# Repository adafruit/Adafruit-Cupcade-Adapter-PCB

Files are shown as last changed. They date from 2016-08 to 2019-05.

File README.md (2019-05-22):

## Adafruit Cupcade Arcade Adapter V1 PCB
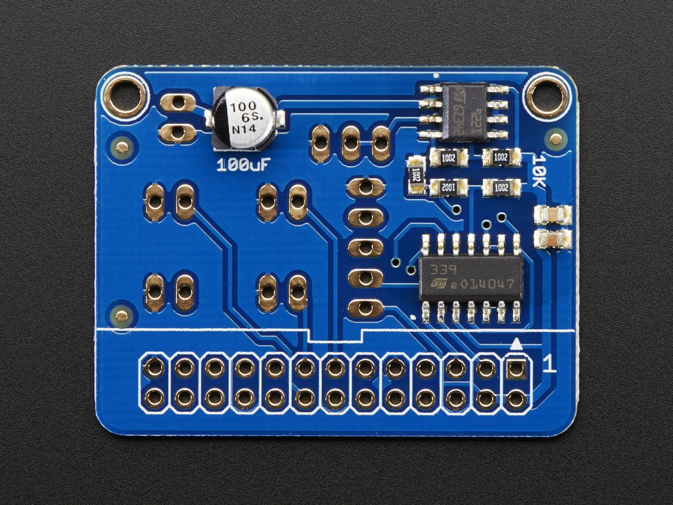
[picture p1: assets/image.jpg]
<a href="http://www.adafruit.com/products/1916"><br/>
Click here to purchase one from the Adafruit shop</a>

This is the PCB and small parts pack from original V1 Cupcade. These parts were used with the original "Raspberry Pi 1" design, not the version for Pi A+, 2, 3, or Zero!

Great for anyone who needs a replacement PCB or wants to mod or build out their Cupcade. 

PCB files for the Adafruit Cupcade Adapter. The format is EagleCAD schematic and board layout
- http://www.adafruit.com/product/1916

### License

Adafruit invests time and resources providing this open source design, please support Adafruit and open-source hardware by purchasing products from [Adafruit](https://www.adafruit.com)!

All text above must be included in any redistribution

Designed by Limor Fried/Ladyada for Adafruit Industries.
Creative Commons Attribution/Share-Alike, all text above must be included in any redistribution. 
See license.txt for additional information.

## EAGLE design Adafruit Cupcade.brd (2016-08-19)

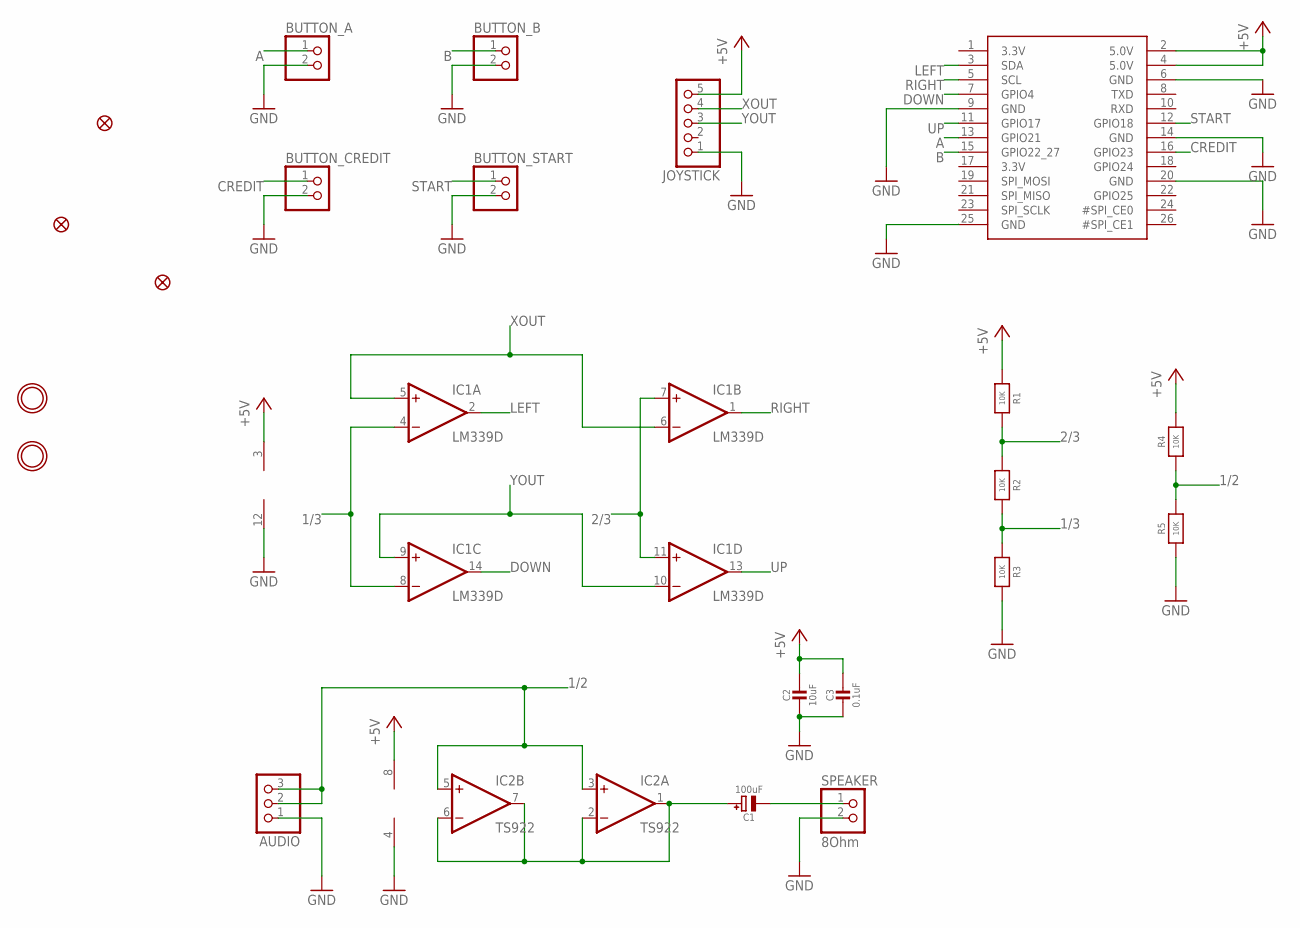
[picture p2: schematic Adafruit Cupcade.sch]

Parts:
AUDIO: HEADER-1X3; 1X03_OVAL
BUTTON_A: HEADER-1X2; 1X02_OVAL
BUTTON_B: HEADER-1X2; 1X02_OVAL
BUTTON_CREDIT: HEADER-1X2; 1X02_OVAL
BUTTON_START: HEADER-1X2; 1X02_OVAL
C1: 100uF; PANASONIC_C
C2: 10uF; 0805-NO
C3: 0.1uF; 0805-NO
FID1, FID2, FID3: FIDUCIAL""; FIDUCIAL_1MM
IC1: LM339D; SO14
IC2: TS922; SO08
JOYSTICK: HEADER-1X5; 1X05_OVAL
JP1: RASBERRYPI_IDC
R1, R2, R3, R4, R5: 10K; 0805-NO
SPEAKER: 8Ohm; 1X02_OVAL
U$2, U$3: MOUNTINGHOLE2.5; MOUNTINGHOLE_2.5_PLATED

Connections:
1/2: AUDIO.2, AUDIO.3, IC2.3 (+IN), IC2.5 (+IN), R4.1, R5.2
1/3: IC1.4 (-IN), IC1.8 (-IN), R2.2, R3.1
2/3: IC1.7 (+IN), IC1.11 (+IN), R1.2, R2.1
+5V: C2.1, C3.1, IC1.3 (V+), IC2.8 (V+), JOYSTICK.5, JP1.2 (5.0V), JP1.4 (5.0V), R1.1, R4.2
A: BUTTON_A.1, JP1.13 (GPIO21)
B: BUTTON_B.1, JP1.15 (GPIO22_27)
CREDIT: BUTTON_CREDIT.1, JP1.16 (GPIO23)
DOWN: IC1.14 (OUT), JP1.7 (GPIO4)
GND: AUDIO.1, BUTTON_A.2, BUTTON_B.2, BUTTON_CREDIT.2, BUTTON_START.2, C2.2, C3.2, IC1.12 (GND), IC2.4 (V-), JOYSTICK.1, JP1.6 (GND), JP1.9 (GND), JP1.14 (GND), JP1.20 (GND), JP1.25 (GND), R3.2, R5.1, SPEAKER.2
LEFT: IC1.2 (OUT), JP1.3 (SDA)
unnamed: C1.-, SPEAKER.1
unnamed: C1.+, IC2.1 (OUT), IC2.2 (-IN), IC2.6 (-IN), IC2.7 (OUT)
RIGHT: IC1.1 (OUT), JP1.5 (SCL)
START: BUTTON_START.1, JP1.12 (GPIO18)
UP: IC1.13 (OUT), JP1.11 (GPIO17)
XOUT: IC1.5 (+IN), IC1.6 (-IN), JOYSTICK.4
YOUT: IC1.9 (+IN), IC1.10 (-IN), JOYSTICK.3

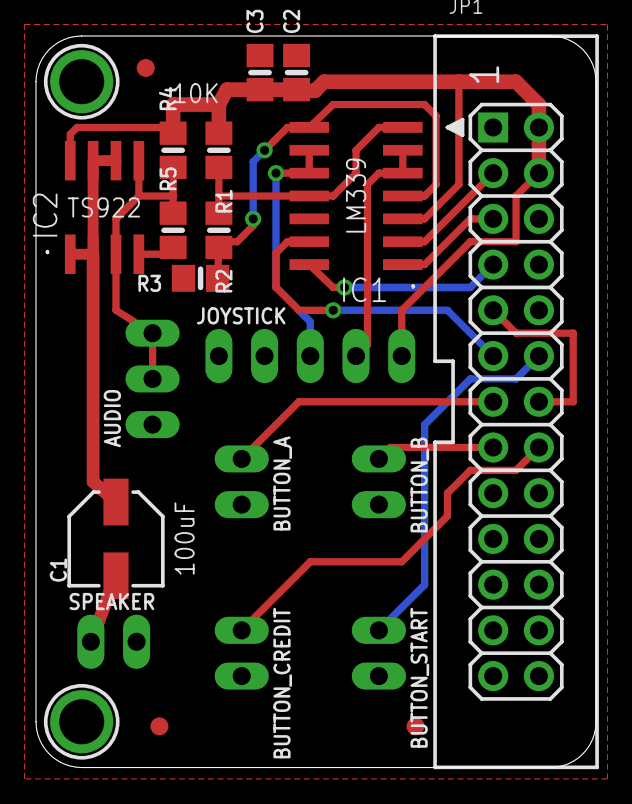
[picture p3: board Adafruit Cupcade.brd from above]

Board: 2 copper layers, 31.1 x 40.6 mm, 24 parts (1 on the bottom side), 17 nets.

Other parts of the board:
U$1: DRAGON_300MIL

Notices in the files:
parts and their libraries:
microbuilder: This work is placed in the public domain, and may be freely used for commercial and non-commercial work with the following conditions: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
